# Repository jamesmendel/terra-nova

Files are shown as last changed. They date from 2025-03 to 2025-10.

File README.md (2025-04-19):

<h1 align="center">TERRA is a companion for mindful wandering</h1>
<h2 align="center">⭐️ This is the working repository for the second generation of TERRA hardware and software. ⭐️</h2>

<br> <!-- Additional spacing -->
<br> <!-- Additional spacing -->

<p align="center">
  TERRA Device
</p>

<br> <!-- Additional spacing -->
<br> <!-- Additional spacing -->

##  Designed with the science of AI and the wisdom of mindfulness, TERRA is the incredible, pocket-sized compass that lets you wander without getting lost. Leave your phone behind and reconnect with your surroundings.

<br> <!-- Additional spacing -->

### Features
- **Improvised Trails, Powered by AI**: Every journey begins with a prompt. TERRA’s sophisticated AI translates your intentions, available time, and precise location into a tailored trail of GPS coordinates. Users don't know where TERRA will take them; the only certainty is finding their way back to the starting point.
- **Wander Without Your Phone**: TERRA invites users to leave their smartphones behind and reconnect with their surroundings. The standalone device boasts a minimalist interface, featuring a tranquil compass needle and gentle haptic feedback to ensure users remain engaged with the present moment.  
- **Open-Source by Design**: TERRA is designed with a DIY mindset. Anyone can download the open-source software, 3D print the CAD designs, assemble the necessary hardware, and start wandering.

<br> <!-- Additional spacing -->

<p align="center">
  ⚠️ <strong>NOTICE</strong>: This project is currently in an experimental phase and is undergoing rapid developments ⚠️
</p>

<br> <!-- Additional spacing -->

### Software

The TERRA App generates coordinates or checkpoints from a starting point and an ideal trail length using the ChatGPT API.

### Running TERRA App Locally

#### Prerequisites 
- `Node.js` v21.5
- `body-parser` v1.20.2
- `cors` v2.8.5
- `express` v4.19.0
- `node-fetch` v3.3.2

To run the TERRA App locally, follow these steps:

1. **Implement ChatGPT API Key:** Obtain a [ChatGPT API key](https://platform.openai.com/) and replace ```YOUR_OPENAI_API_KEY``` with it in the ```server.js``` file.
2. **Implement Google Maps API Key:** Obtain a [Google Places API key](https://developers.google.com/maps/documentation/places/web-service/overview) and replace ```YOUR_MAPS_KEY``` with it in the ```index.js``` file.
3. **Run Locally:** To run the application, use the command:
    ```
    node server.js
    ```
4. **Load Application:** Open `index.html` in a browser to use the app for generating a route.
5. **Download config.h File:** Download the `config.h` file which contains the generated route configuration.
6. **Update Arduino Code:** Replace the `config.h` file in the Arduino code directory with the newly downloaded file.

### Hardware

The hardware for the TERRA project is based on an ESP32 device, equipped with a range of sensors for navigation and interaction.

### Components

The main components required are:

- ESP32 Feather V2 [link](https://learn.adafruit.com/adafruit-esp32-feather-v2/pinouts)
- Waveshare 1.28" Round LCD Display Module with GC9A01 Driver [link](https://www.waveshare.com/1.28inch-lcd-module.htm)
- Adafruit Push-button Power Switch [link](https://thepihut.com/products/adafruit-push-button-power-switch-breakout)
- Beitian BN 880 GPS module [link](https://store.beitian.com/products/beitian-compass-qmc5883l-amp2-6-pix4-pixhawk-gnss-gps-glonass-dual-flight-control-gps-module-bn-880q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)
- Adafruit DRV2605L Haptic Controller Breakout [link](https://learn.adafruit.com/adafruit-drv2605-haptic-controller-breakout/arduino-code)
- CMPS12 Compass [link](https://www.robot-electronics.co.uk/cmps12-tilt-compensated-magnetic-compass.html)
- Round Battery
- USB C charging port extender

### Wiring
Connect the components together in the following order:

| ESP32 Pin | Screen | Motor Driver | Compass | GPS | Push Button |
| --- | --- | --- | --- | --- | --- |
| 3V | VCC | VIN | VIN | VIN | |
| GND | GND | GND | GND | GND | GND |
| 19 (MOSI) | DIN | | | | |
| 4 (A5) | RST | | | | |
| 5 (SCK) | CLK | | | | |
| 12 | BL | | | | |
| 15 | CS | | | | |
| 32 (A7) | | | | | OFF |
| 33 | DC | | | | |
| SDA | | SDA | SDA | | |
| SCL | | SCL | SCL | | |
| RX | | | | TX  | |
| TX | | | | RX  | |

## Arduino Code

To run the Arduino code, you will need to set up the ESP32 board and install the necessary libraries.

### Setup Steps

1. **ESP32 Arduino Setup:** Add the ESP32 board to the Arduino IDE.
    - Go to **Arduino > Preferences**.
    - Add the following URL to the **Additional Boards Manager URLs**:
      ```
      https://raw.githubusercontent.com/espressif/arduino-esp32/gh-pages/package_esp32_dev_index.json
      ```
    - Select **Adafruit Feather ESP32 V2** as the board.

2. **Install Libraries:** Install the following libraries through the Library Manager in the Arduino IDE.
    - `TinyGPSPlus.h`
    - `TFT_eSPI.h`
    - `Adafruit_DRV2605.h`

3. **Upload the Code:** After installing the libraries and updating the `config.h` file with new coordinates, upload the code to the ESP32 device. The device should work without further adjustments.

4. **Debug Mode:** A `debugMode` flag is available in the code. To test the device with manual coordinates, set this flag to `true` and input coordinates into the serial monitor.

### Further Customizations

You can use your own checkpoint files by converting black and white images into a compatible format.

#### Using Your Own Checkpoint Files

- Convert static black and white, 240x240PX `.bmp` images to `.XBM` format using [this online tool](https://www.online-utility.org/image/convert/to/XBM).
- Open the XBM file in a text editor and copy the hexadecimal values included in the curly brackets.
- Replace the existing files in the `images/checkpoints` directory with your customized `.h` file.

### Contributors
Vision + Concept: Modem<br> 
Industrial Design: Panter&Tourron<br> 
Software + Hardware: Alice Stewart<br> 
Product Renderings: Côme Lart<br> 
Illustrations: Hugo Bernier<br> 
Campaign Teaser: Michael Willis

### License
TERRA is licensed under the GNU General Public License v3.0 © 2024 Modem

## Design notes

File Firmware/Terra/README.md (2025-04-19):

Clone Firmware repo:
```bash
git clone --filter=blob:none --no-checkout https://github.com/jamesmendel/terra-nova.git
cd terra-nova
git sparse-checkout init --cone
git sparse-checkout set Firmware
git checkout main
```

Install PlatformIO

Initialize the project:
```bash
cd Firmware/Terra
pio init --ide vscode
```

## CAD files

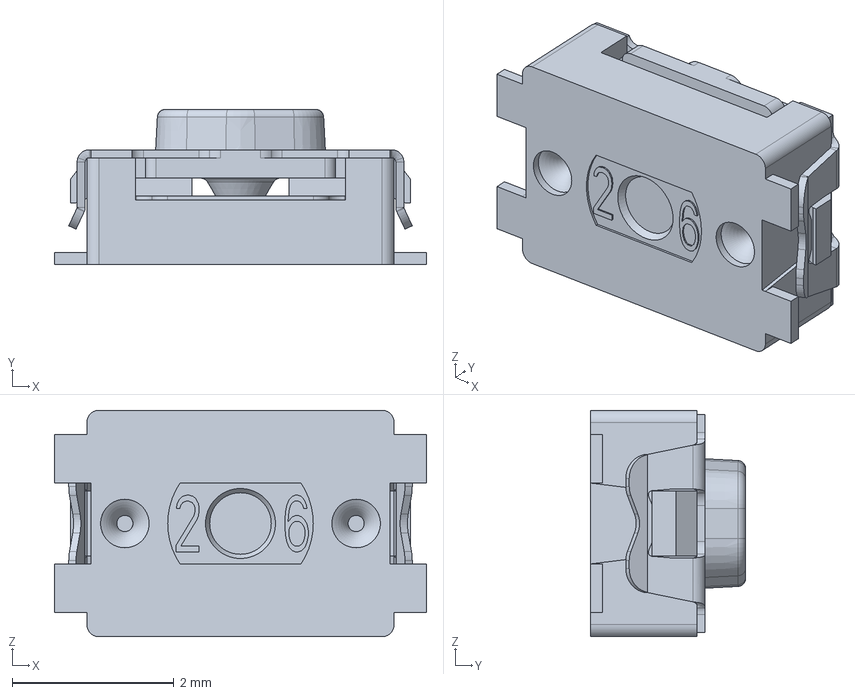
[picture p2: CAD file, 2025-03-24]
Hardware/Symbols/CKCOMPONENTS_KMR231NGULCLFS/KMR231NGULCLFS.stp
4.60 x 1.92 x 2.80 mm

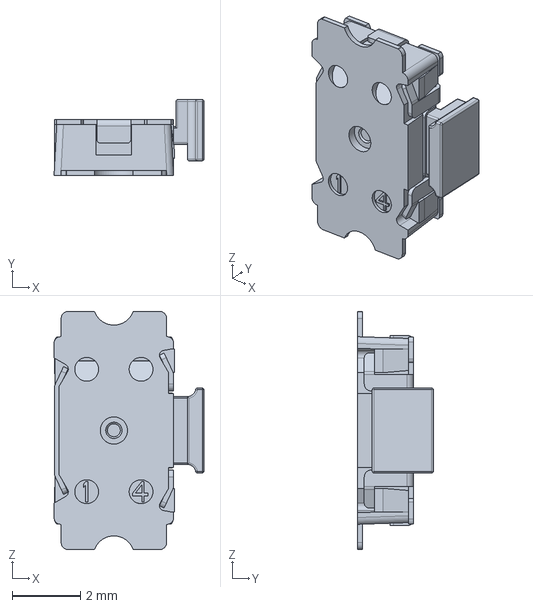
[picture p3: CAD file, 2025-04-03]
Hardware/Symbols/CKCOMPONENTS_KSS323GLFG/KSS323GLFG.stp
4.41 x 2.23 x 7.00 mm

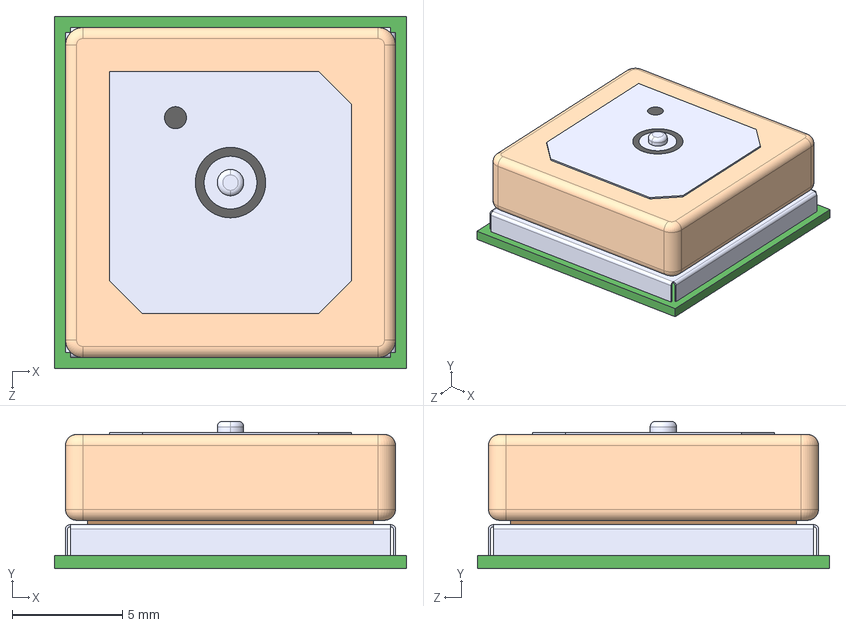
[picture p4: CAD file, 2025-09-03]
Hardware/Symbols/TESO-LIV3F/PA1616D.STEP
16.0 x 6.70 x 16.0 mm

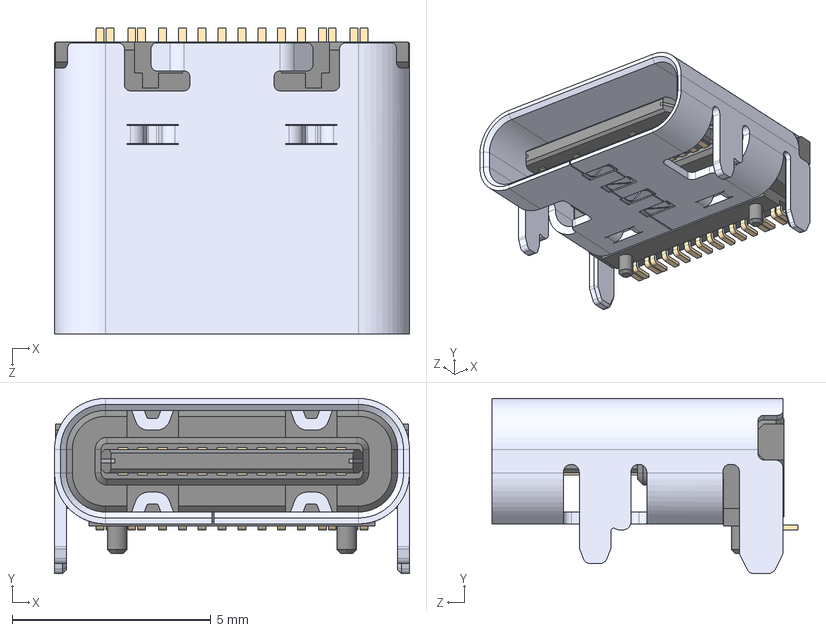
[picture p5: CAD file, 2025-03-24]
Hardware/Symbols/USB4105-GF-A.step
8.94 x 4.41 x 7.71 mm

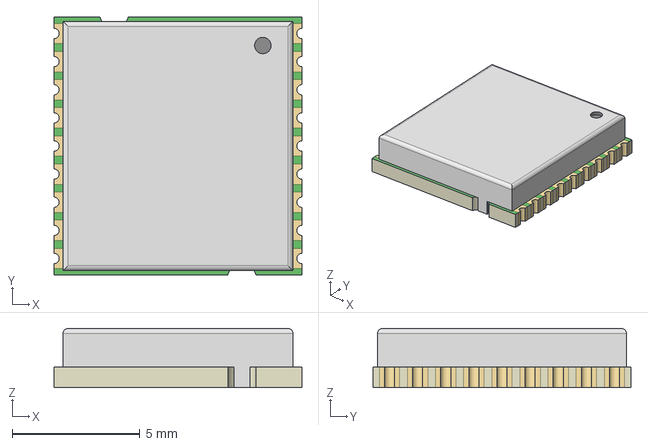
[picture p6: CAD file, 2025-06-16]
Hardware/Symbols/TESO-LIV3F/TESEO-LIV3R.stp
9.70 x 10.1 x 2.31 mm

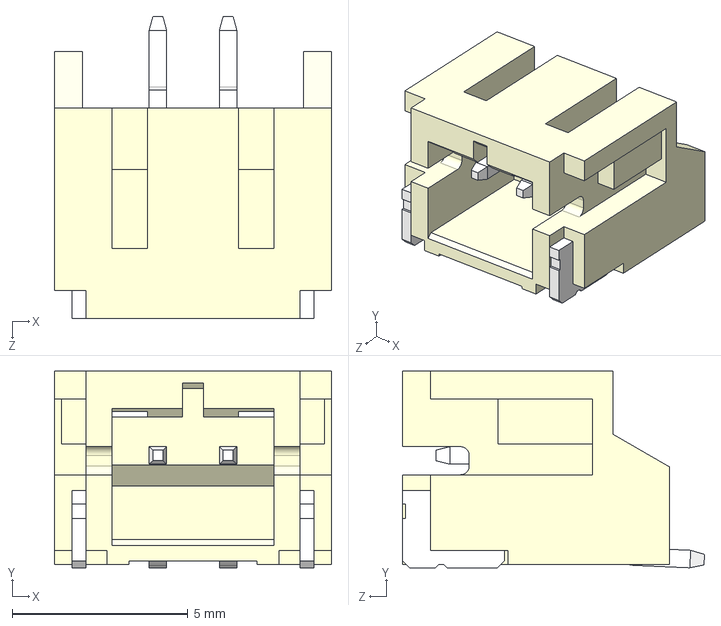
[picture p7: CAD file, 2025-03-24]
Hardware/Symbols/S2B-PH-SM4-TB.step
7.90 x 5.60 x 8.60 mm

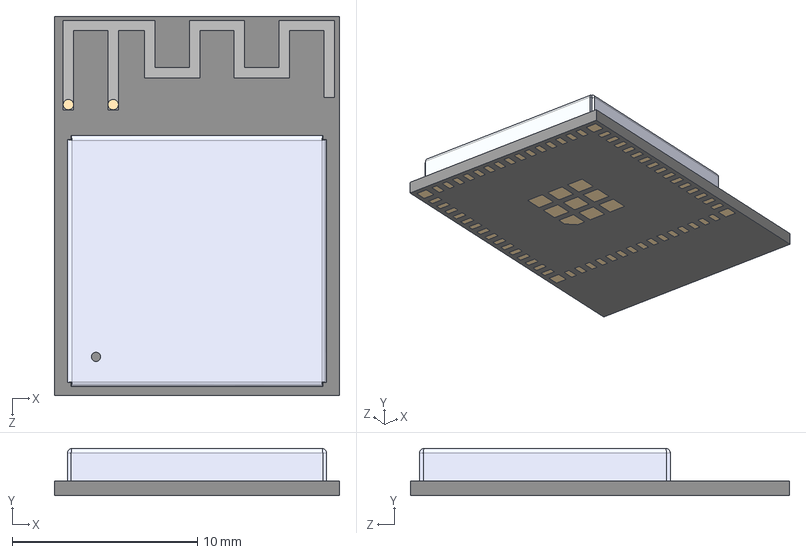
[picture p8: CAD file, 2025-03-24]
Hardware/Symbols/ESP32-S3-MINI-1-N8.step
15.4 x 2.55 x 20.5 mm

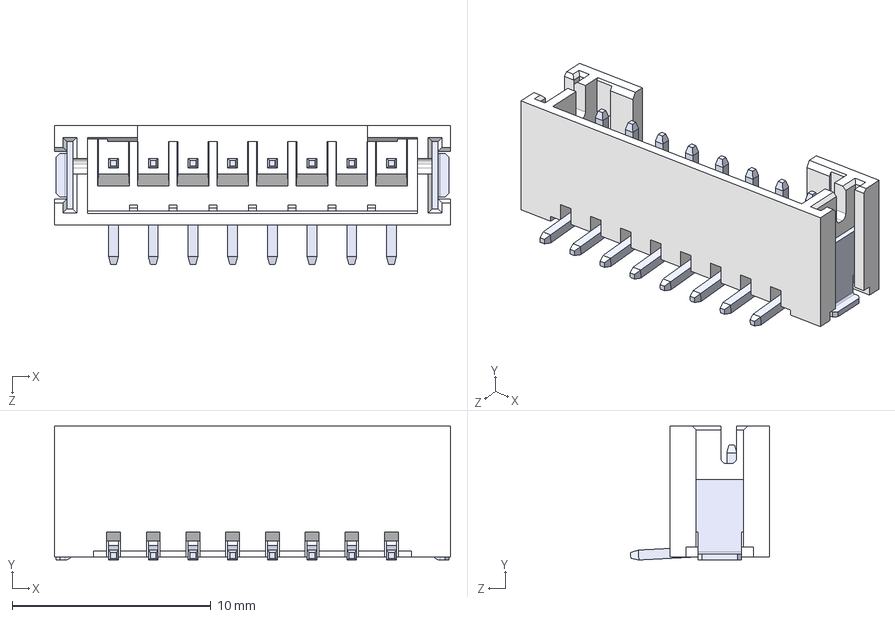
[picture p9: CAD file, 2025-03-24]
Hardware/Symbols/JST_PH_B8B-PH-SM4-TB_Vertical.STEP
20.0 x 6.75 x 7.00 mm
BxB-PH-SM4 body_8
BxB-PH-SM4 tab x 2
BxB-PH-SM4 pin x 8

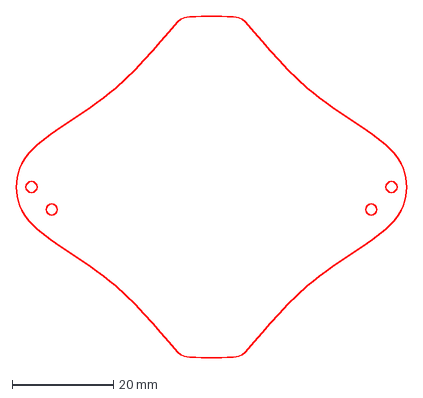
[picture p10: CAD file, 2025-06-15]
Hardware/Artwork/Outline/250506_Terra PCB Outline.dxf
76.9 x 67.3 mm

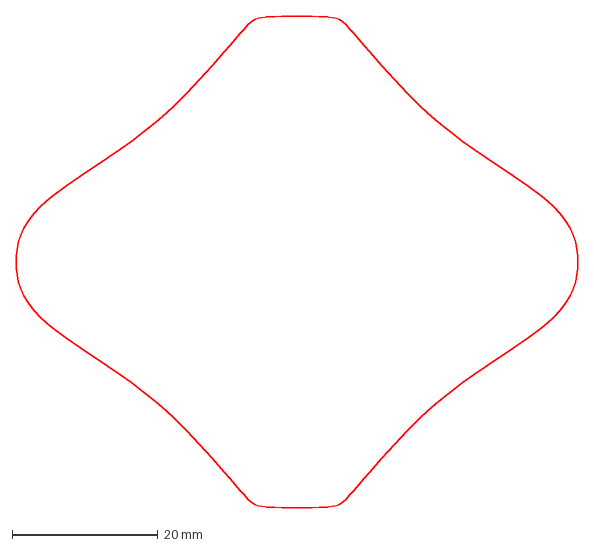
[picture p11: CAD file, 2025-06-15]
Hardware/Artwork/Outline/250506_Terra PCB Outline Only.dxf
76.9 x 67.3 mm

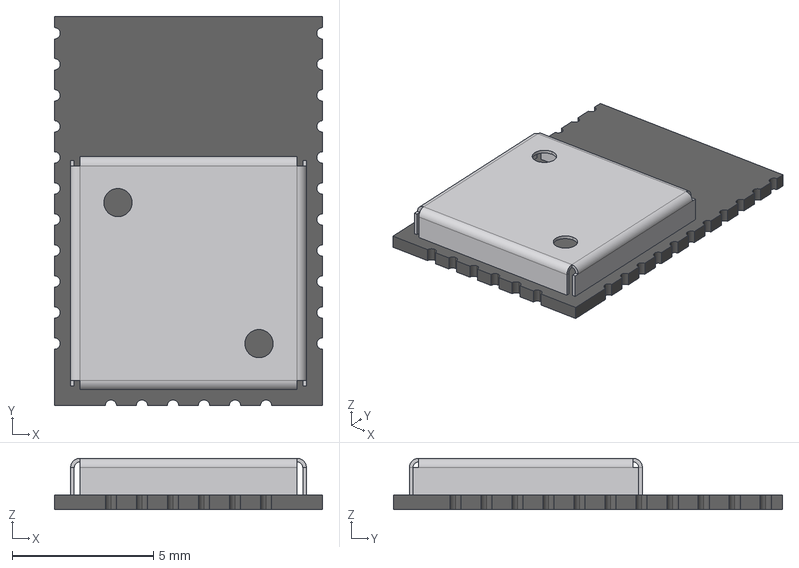
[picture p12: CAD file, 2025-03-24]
Hardware/Symbols/M20048-1_wshielding.step
9.50 x 13.8 x 1.82 mm

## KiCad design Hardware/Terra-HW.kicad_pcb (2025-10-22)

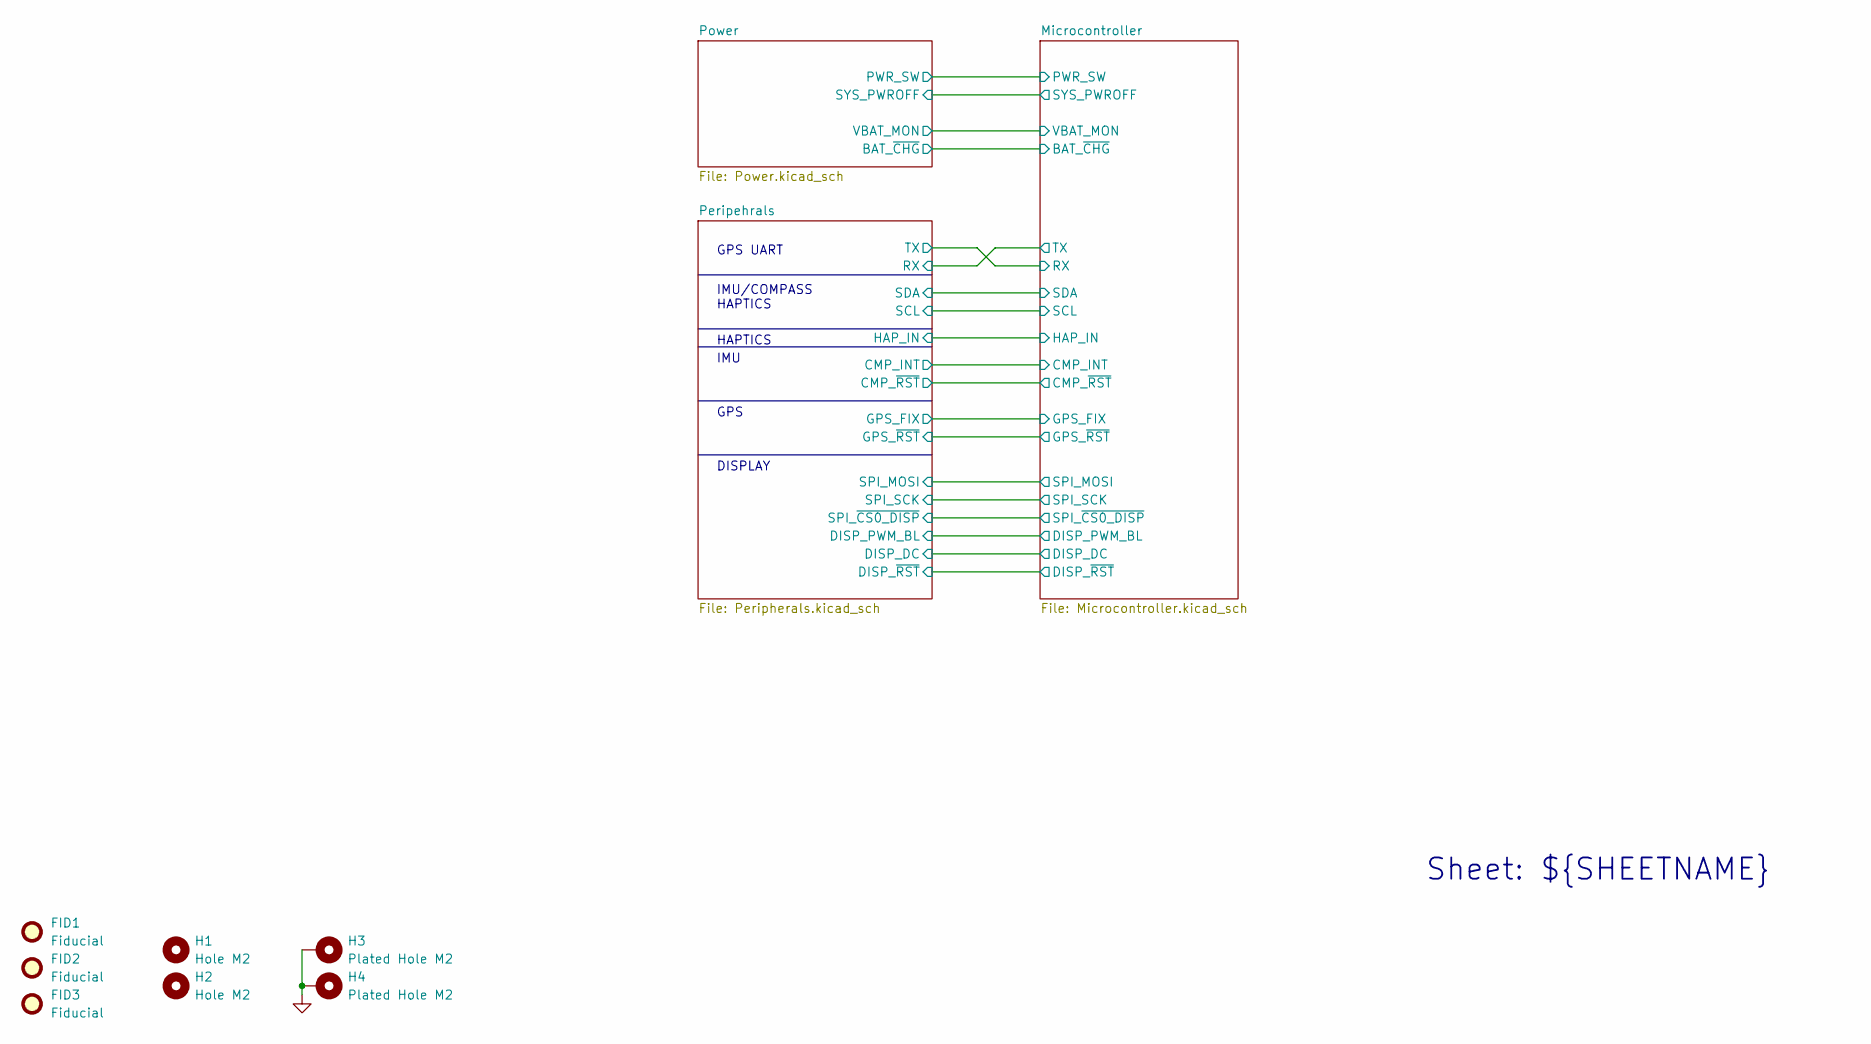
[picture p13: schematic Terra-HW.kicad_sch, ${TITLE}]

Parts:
FID1, FID2, FID3: Fiducial; Fiducial_1mm_Mask2mm
H1, H2: Hole M2; MountingHole_2.2mm_M2
H3, H4: Plated Hole M2; MountingHole_2.2mm_M2_Pad

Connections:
GND: H3.1, H4.1; also elsewhere on the board

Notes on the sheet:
HAPTICS
GPS UART
IMU
DISPLAY
IMU/COMPASS HAPTICS
GPS
Sheet: ${SHEETNAME}

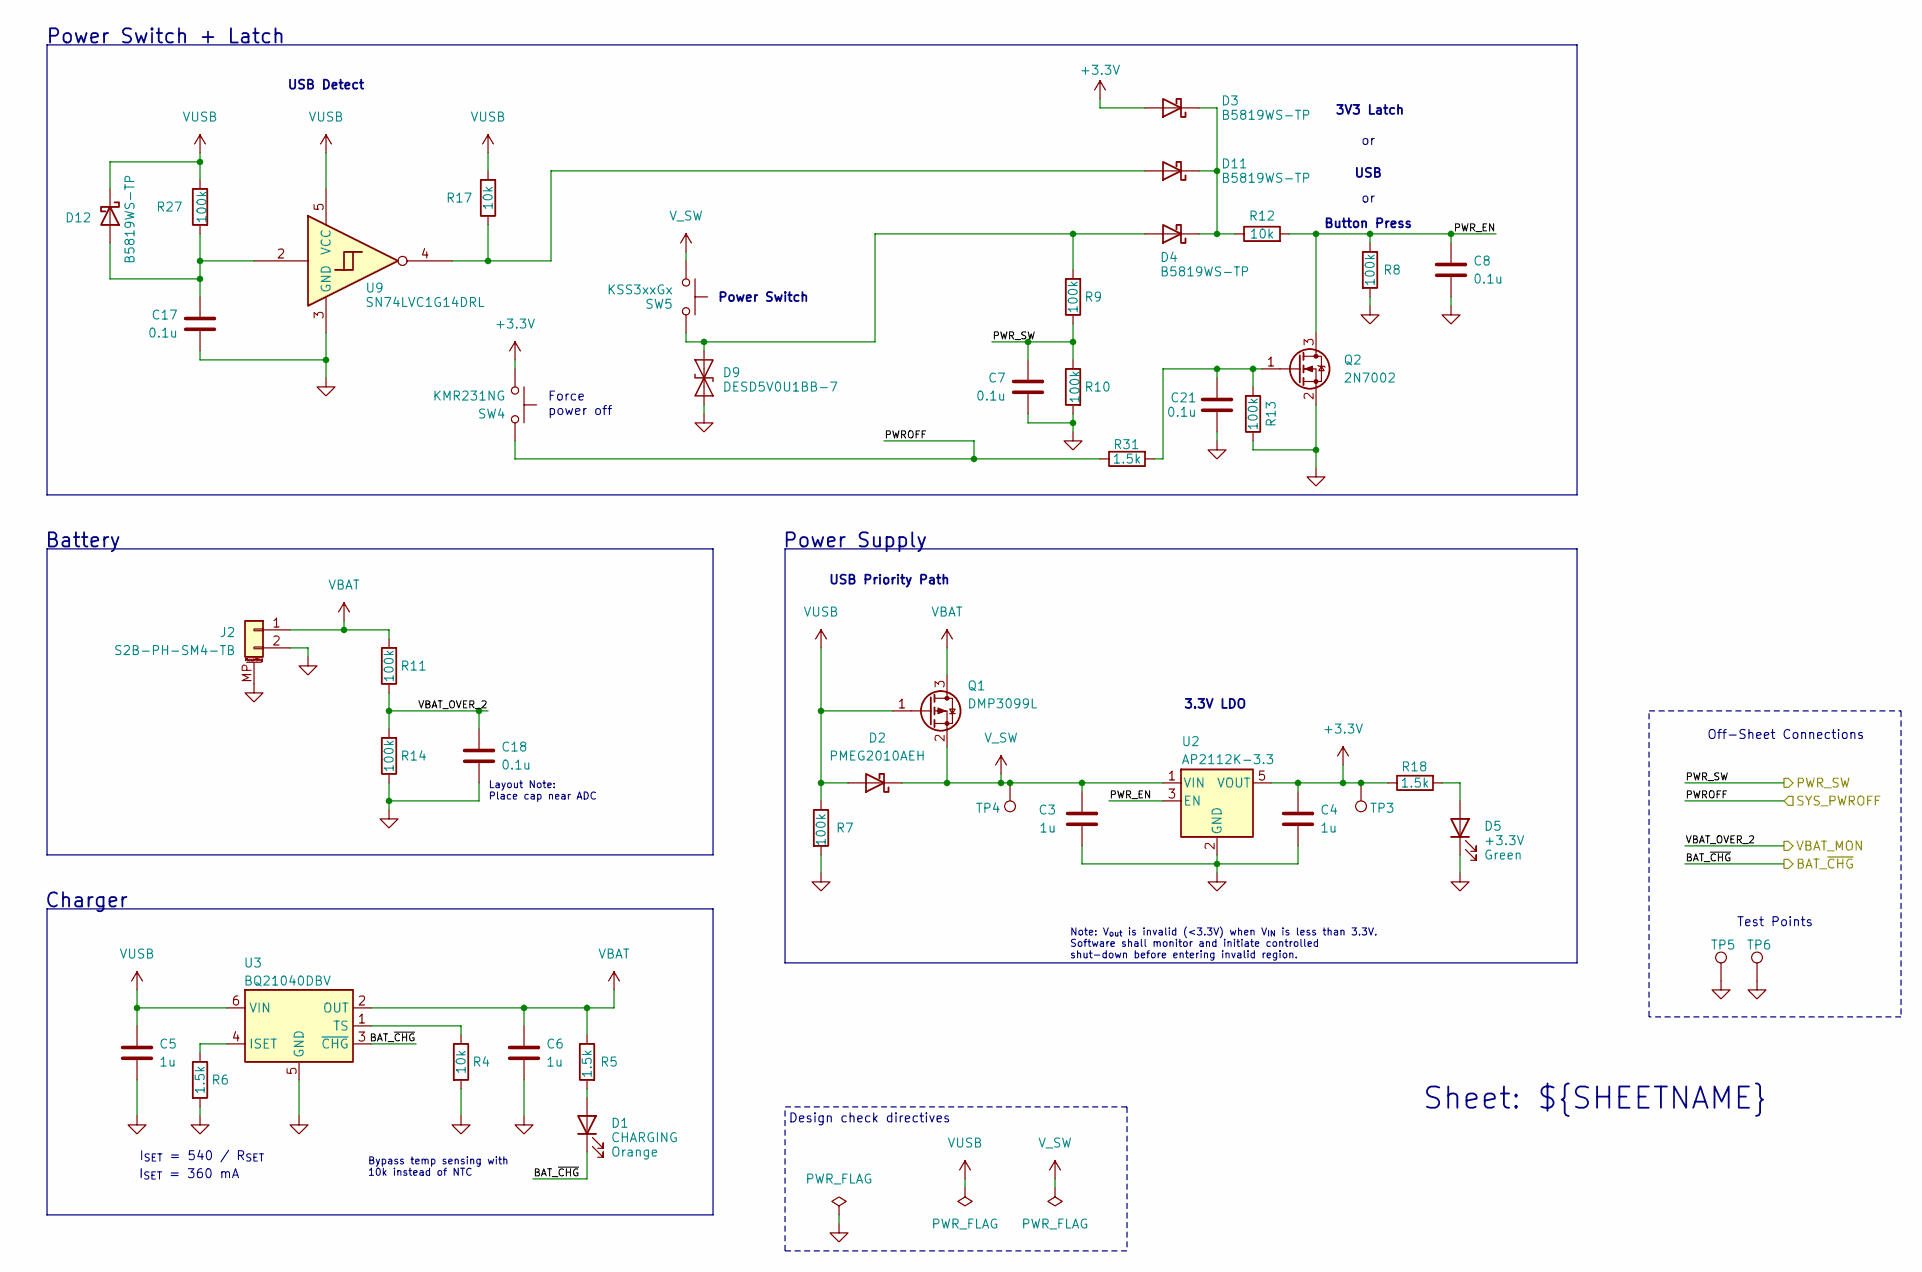
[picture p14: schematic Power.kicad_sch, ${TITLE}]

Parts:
C3, C4, C5, C6: 1u; C_0603_1608Metric; MPN CL10A105KO8NNNC
C7, C8, C17, C18, C21: 0.1u; C_0603_1608Metric; MPN CL10B104KO8NNNC
D1: CHARGING; D_0603_1608Metric; MPN LTST-C190KFKT
D2: PMEG2010AEH; D_SOD-123; MPN PMEG2010AEH
D3, D4, D11, D12: B5819WS-TP; D_SOD-323; MPN B5819WS-TP
D5: +3.3V; D_0603_1608Metric; MPN LTST-C190GKT
D9: DESD5V0U1BB-7; D_SOD-523; MPN DESD5V0U1BB-7
J2: S2B-PH-SM4-TB; JST_PH_S2B-PH-SM4-TB_1x02-1MP_P2.00mm_Horizontal; MPN S2B-PH-SM4-TB
Q1: DMP3099L; SOT-23; MPN DMP3099L
Q2: 2N7002; SOT-23; MPN 2N7002
R4, R12, R17: 10k; R_0603_1608Metric; MPN RC0603FR-0710KL
R5, R6, R18, R31: 1.5k; R_0603_1608Metric; MPN RC0603FR-071K5L
R7, R8, R9, R10, R11, R13, R14, R27: 100k; R_0603_1608Metric; MPN RC0603FR-07100KL
SW4: KMR231NG; SW_Push_1P1T_NO_CK_KMR2; MPN KMR231NG
SW5: KSS3xxGx; SW_KSS323_CNK; MPN KSS321GLFS
TP3: 3.3V; TestPoint_Pad_D1.5mm_WITH_LABEL
TP4: V_SW; TestPoint_Pad_D1.5mm_WITH_LABEL
TP5, TP6: GND; TestPoint_Pad_D1.5mm_WITH_LABEL
U2: AP2112K-3.3; SOT-23-5; MPN AP2112K-3.3TRG1
U3: BQ21040DBV; SOT-23-6; MPN BQ21040DBV
U9: SN74LVC1G14DRL; SOT-553; MPN SN74LVC1G14DRL

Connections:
+3.3V: C4.1, D3.2 (A), R18.1, SW4.1, TP3.1, U2.5 (VOUT); also elsewhere on the board
/Microcontroller/BAT_~CHG: D1.1 (K), U3.3 (~CHG); also elsewhere on the board
/Microcontroller/PWROFF: R31.1, SW4.2; also elsewhere on the board
/Microcontroller/PWR_SW: C7.1, R9.1, R10.1; also elsewhere on the board
/Microcontroller/VBAT_OVER_2: C18.1, R11.1, R14.2; also elsewhere on the board
/Power/PWR_EN: C8.1, Q2.3 (D), R8.1, R12.2, U2.3 (EN)
GND: C3.2, C4.2, C5.2, C6.2, C7.2, C8.2, C17.2, C18.2, C21.2, D5.1 (K), D9.1 (A1), J2.2, J2.MP (MountPin), Q2.2 (S), R4.2, R6.2, R7.2, R8.2, R10.2, R13.1, R14.1, TP5.1, TP6.1, U2.2 (GND), U3.5 (GND), U9.3 (GND); also elsewhere on the board
unnamed: D1.2 (A), R5.2
unnamed: D4.2 (A), D9.2 (A2), R9.2, SW5.2
unnamed: D5.2 (A), R18.2
unnamed: D11.2 (A), R17.1, U9.4
unnamed: D3.1 (K), D4.1 (K), D11.1 (K), R12.1
unnamed: C17.1, D12.2 (A), R27.2, U9.2
unnamed: C21.1, Q2.1 (G), R13.2, R31.2
unnamed: R6.1, U3.4 (ISET)
unnamed: R4.1, U3.1 (TS)
VBAT: C6.1, J2.1, Q1.3 (D), R5.1, R11.2, U3.2 (OUT); also elsewhere on the board
VUSB: C5.1, D2.2 (A), D12.1 (K), Q1.1 (G), R7.1, R17.2, R27.1, U3.6 (VIN), U9.5 (VCC); also elsewhere on the board
V_SW: C3.1, D2.1 (K), Q1.2 (S), SW5.1, TP4.1, U2.1 (VIN)

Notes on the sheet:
Power Switch
Power Supply
I_{SET} = 540 / R_{SET}
3V3 Latch
3.3V LDO
USB Priority Path
Note: V_{out} is invalid (<3.3V) when V_{IN} is less than 3.3V. Software shall monitor and initiate controlled shut-down before entering invalid region.
Force power off
Test Points
Bypass temp sensing with 10k instead of NTC
Charger
Design check directives
I_{SET} = 360 mA
Button Press
Layout Note: Place cap near ADC
USB Detect
Battery
Off-Sheet Connections
USB
Power Switch + Latch
Sheet: ${SHEETNAME}

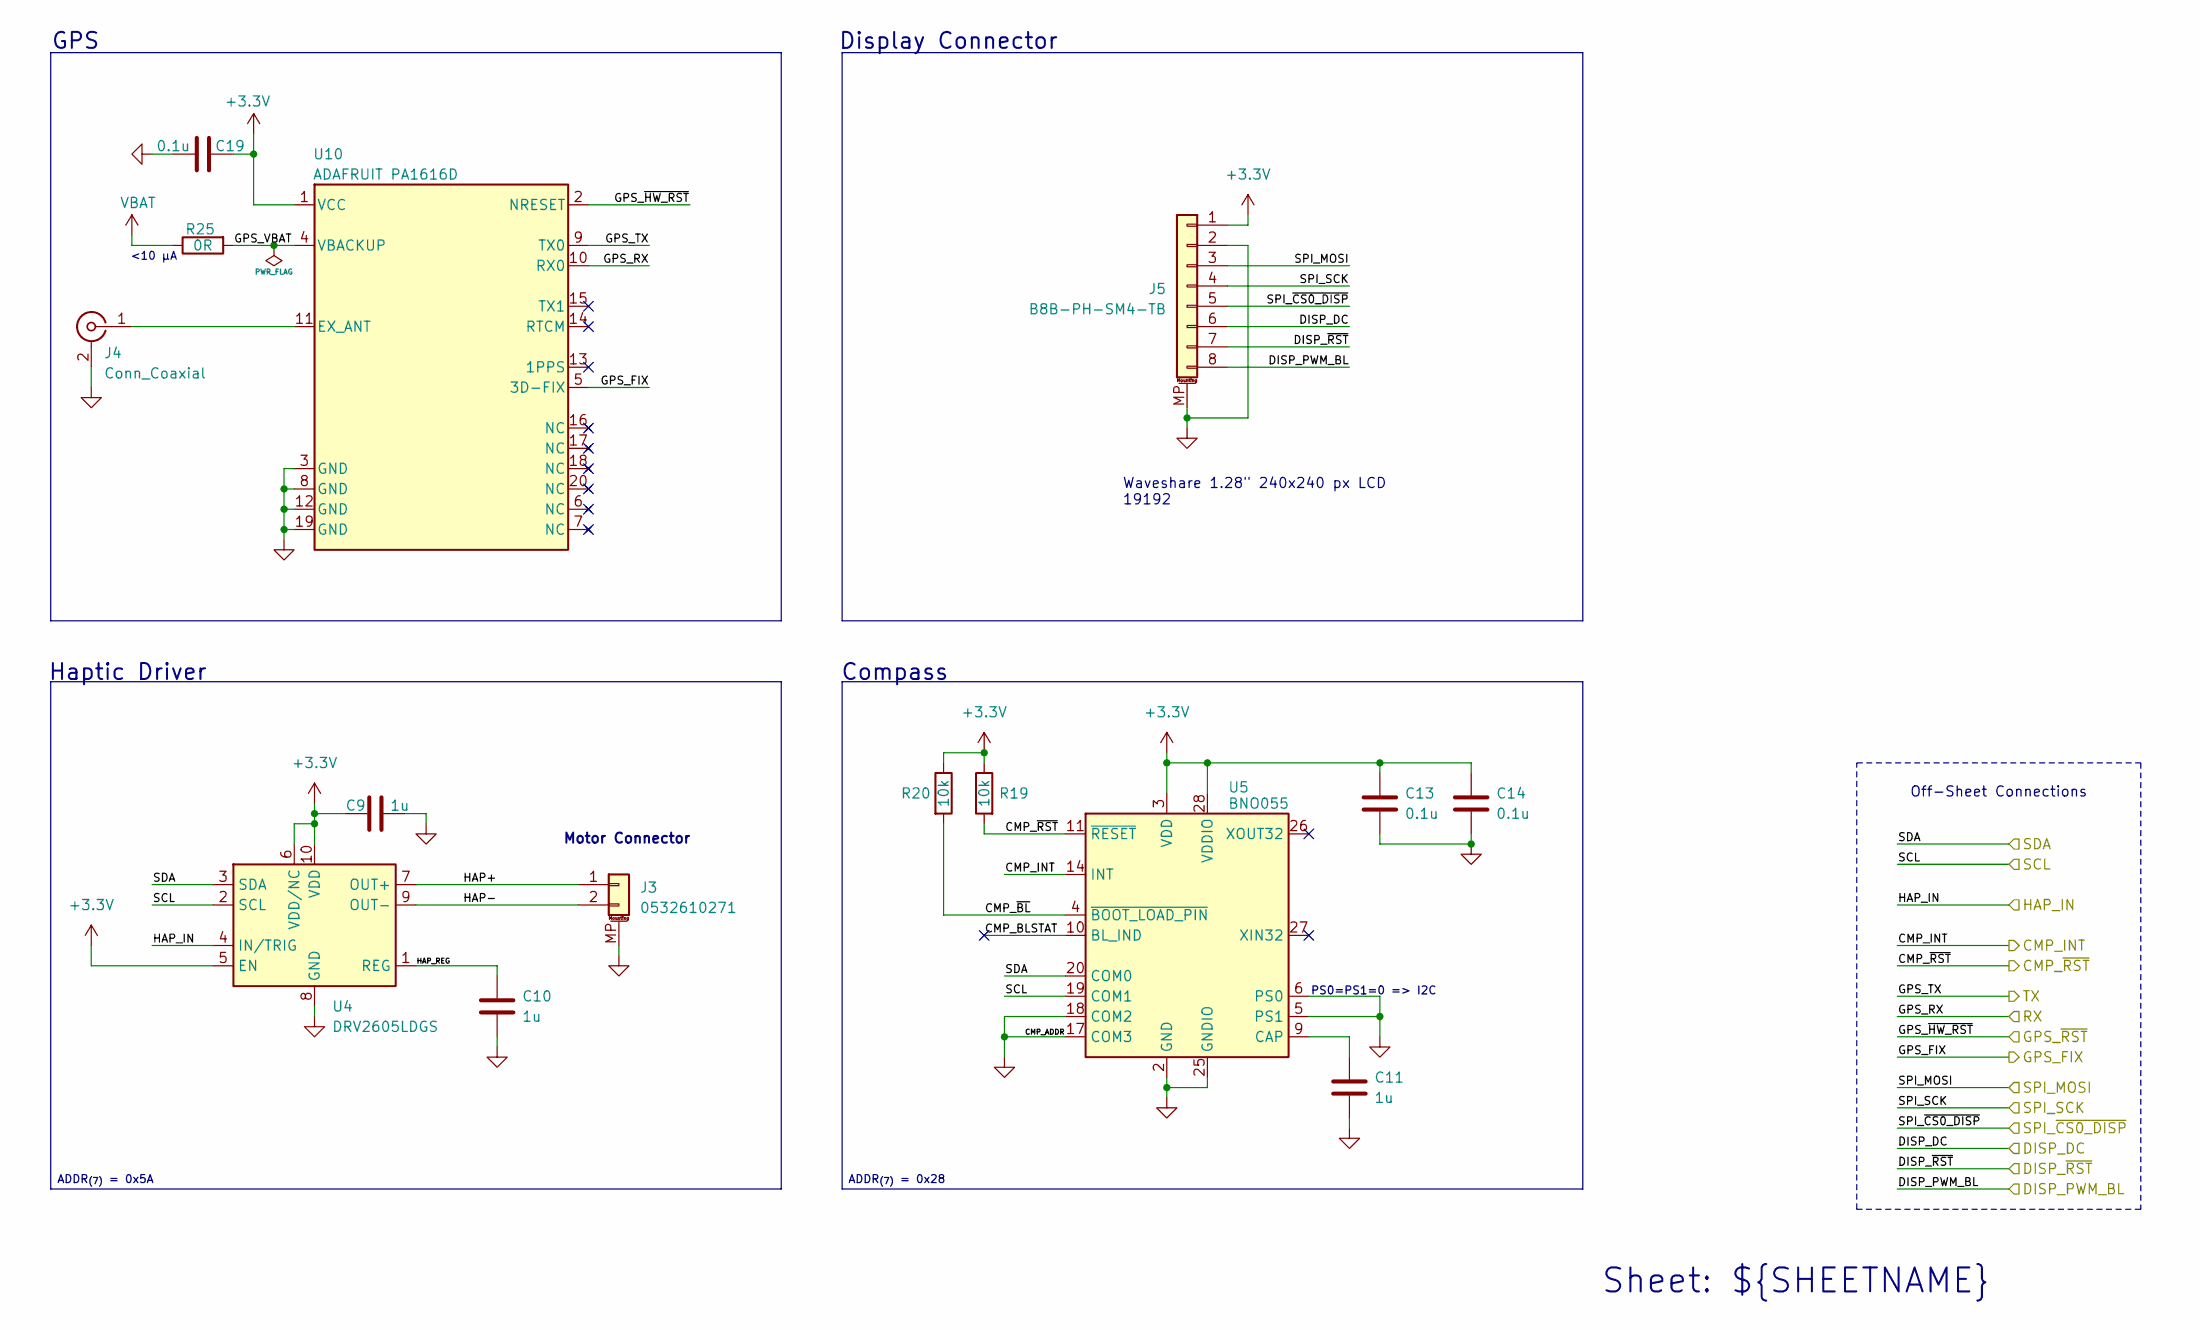
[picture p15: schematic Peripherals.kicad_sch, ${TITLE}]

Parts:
C9, C10, C11: 1u; C_0603_1608Metric; MPN CL10A105KO8NNNC
C13, C14, C19: 0.1u; C_0603_1608Metric; MPN CL10B104KO8NNNC
J3: 0532610271; Molex_PicoBlade_53261-0271_1x02-1MP_P1.25mm_Horizontal; MPN 0532610271
J4: Conn_Coaxial; U.FL_Molex_MCRF_73412-0110_Vertical; MPN CONMHF1-SMD-T
J5: B8B-PH-SM4-TB; JST_PH_B8B-PH-SM4-TB_1x08-1MP_P2.00mm_Vertical; MPN B8B-PH-SM4-TB
R19, R20: 10k; R_0603_1608Metric; MPN RC0603FR-0710KL
R25: 0R; R_0603_1608Metric; MPN RC0603FR-070RL
U4: DRV2605LDGS; VSSOP-10_3x3mm_P0.5mm; MPN DRV2605LDGS
U5: BNO055; LGA-28_5.2x3.8mm_P0.5mm; MPN BNO055
U10: ADAFRUIT PA1616D; PA1616D; MPN 5186

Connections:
+3.3V: C9.1, C13.1, C14.1, C19.1, J5.1, R19.1, R20.1, U4.5 (EN), U4.6 (VDD/NC), U4.10 (VDD), U5.3 (VDD), U5.28 (VDDIO), U10.1 (VCC); also elsewhere on the board
/Microcontroller/CMP_INT: U5.14 (INT); also elsewhere on the board
/Microcontroller/CMP_~RST: R19.2, U5.11 (~RESET); also elsewhere on the board
/Microcontroller/DISP_DC: J5.6; also elsewhere on the board
/Microcontroller/DISP_PWM_BL: J5.8; also elsewhere on the board
/Microcontroller/DISP_~RST: J5.7; also elsewhere on the board
/Microcontroller/GPS_FIX: U10.5 (3D-FIX); also elsewhere on the board
/Microcontroller/GPS_~RST: U10.2 (NRESET); also elsewhere on the board
/Microcontroller/HAPTIC_IN_TRG: U4.4 (IN/TRIG); also elsewhere on the board
/Microcontroller/I2C_SCL: U4.2 (SCL), U5.19 (COM1); also elsewhere on the board
/Microcontroller/I2C_SDA: U4.3 (SDA), U5.20 (COM0); also elsewhere on the board
/Microcontroller/SPI_MOSI: J5.3; also elsewhere on the board
/Microcontroller/SPI_SCK: J5.4; also elsewhere on the board
/Microcontroller/SPI_~CS0_DISP: J5.5; also elsewhere on the board
/Microcontroller/U1RXD: U10.9 (TX0); also elsewhere on the board
/Microcontroller/U1TXD: U10.10 (RX0); also elsewhere on the board
/Peripehrals/CMP_BLSTAT: U5.10 (BL_IND)
/Peripehrals/CMP_~BL: R20.2, U5.4 (~BOOT_LOAD_PIN)
/Peripehrals/GPS_VBAT: R25.2, U10.4 (VBACKUP)
/Peripehrals/HAP+: J3.1, U4.7 (OUT+)
/Peripehrals/HAP-: J3.2, U4.9 (OUT-)
/Peripehrals/HAP_REG: C10.1, U4.1 (REG)
GND: C9.2, C10.2, C11.2, C13.2, C14.2, C19.2, J3.MP (MountPin), J4.2 (Ext), J5.2, J5.MP (MountPin), U4.8 (GND), U5.2 (GND), U5.5 (PS1), U5.6 (PS0), U5.17 (COM3), U5.18 (COM2), U5.25 (GNDIO), U10.3 (GND), U10.8 (GND), U10.12 (GND), U10.19 (GND); also elsewhere on the board
unnamed: J4.1 (In), U10.11 (EX_ANT)
unnamed: C11.1, U5.9 (CAP)
VBAT: R25.1; also elsewhere on the board

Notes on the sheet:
ADDR_{(7)} = 0x5A
ADDR_{(7)} = 0x28
Off-Sheet Connections
Waveshare 1.28" 240x240 px LCD 19192
Motor Connector
Compass
GPS
<10 μA
PS0=PS1=0 => I2C
Haptic Driver
Display Connector
Sheet: ${SHEETNAME}

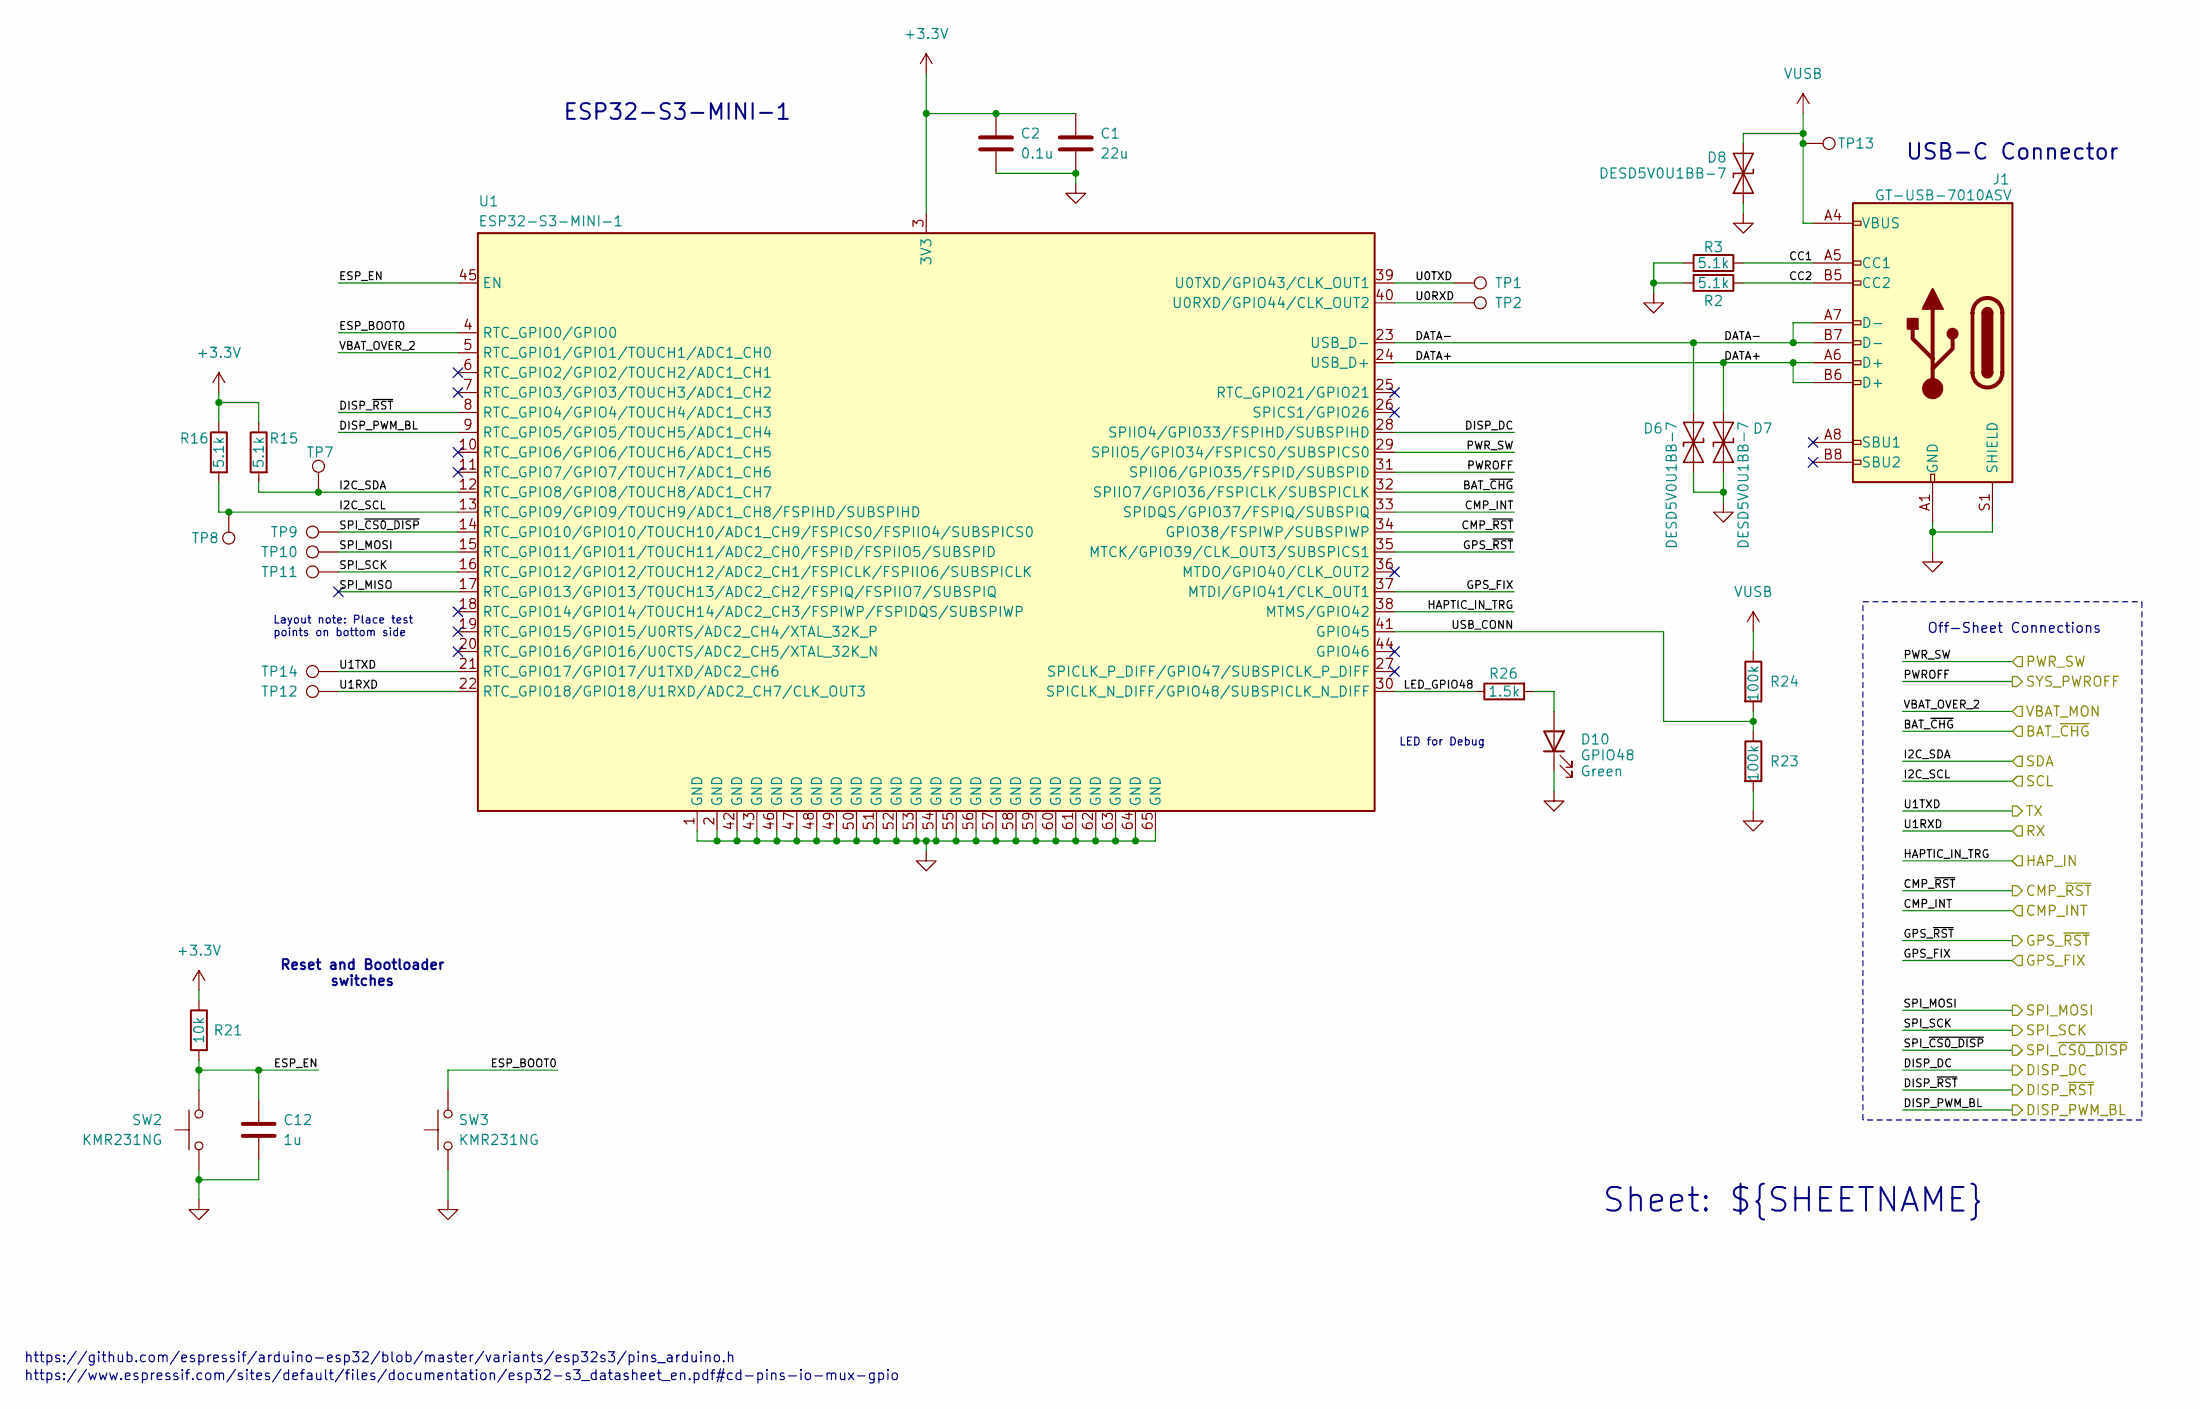
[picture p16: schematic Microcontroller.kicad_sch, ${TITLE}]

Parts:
C1: 22u; C_0603_1608Metric; MPN CL10A226MP8NUNE
C2: 0.1u; C_0603_1608Metric; MPN CL10B104KO8NNNC
C12: 1u; C_0603_1608Metric; MPN CL10A105KO8NNNC
D6, D7, D8: DESD5V0U1BB-7; D_SOD-523; MPN DESD5V0U1BB-7
D10: GPIO48; D_0603_1608Metric; MPN LTST-C190GKT
J1: GT-USB-7010ASV; USB_C_Receptacle_G-Switch_GT-USB-7010ASV; MPN GT-USB-7010ASV
R2, R3, R15, R16: 5.1k; R_0603_1608Metric; MPN RC0603FR-075K1L
R21: 10k; R_0603_1608Metric; MPN RC0603FR-0710KL
R23, R24: 100k; R_0603_1608Metric; MPN RC0603FR-07100KL
R26: 1.5k; R_0603_1608Metric; MPN RC0603FR-071K5L
SW2, SW3: KMR231NG; SW_Push_1P1T_NO_CK_KMR2; MPN KMR231NG
TP1: TXD0; TestPoint_Pad_D1.5mm_WITH_LABEL
TP2: RXD0; TestPoint_Pad_D1.5mm_WITH_LABEL
TP7: I2C_SDA; TestPoint_Pad_D1.5mm_WITH_LABEL
TP8: I2C_SCL; TestPoint_Pad_D1.5mm_WITH_LABEL
TP9: SPI_CS0; TestPoint_Pad_D1.5mm_WITH_LABEL
TP10: SPI_MOSI; TestPoint_Pad_D1.5mm_WITH_LABEL
TP11: SPI_SCK; TestPoint_Pad_D1.5mm_WITH_LABEL
TP12: RXD1; TestPoint_Pad_D1.5mm_WITH_LABEL
TP13: VUSB; TestPoint_Pad_D1.5mm_WITH_LABEL
TP14: TXD1; TestPoint_Pad_D1.5mm_WITH_LABEL
U1: ESP32-S3-MINI-1; ESP32-S2-MINI-1; MPN ESP32-S3-MINI-1-N4R2

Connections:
+3.3V: C1.1, C2.1, R15.1, R16.1, R21.1, U1.3 (3V3); also elsewhere on the board
/Microcontroller/BAT_~CHG: U1.32 (SPIIO7/GPIO36/FSPICLK/SUBSPICLK); also elsewhere on the board
/Microcontroller/CC1: J1.A5 (CC1), R3.1
/Microcontroller/CC2: J1.B5 (CC2), R2.1
/Microcontroller/CMP_INT: U1.33 (SPIDQS/GPIO37/FSPIQ/SUBSPIQ); also elsewhere on the board
/Microcontroller/CMP_~RST: U1.34 (GPIO38/FSPIWP/SUBSPIWP); also elsewhere on the board
/Microcontroller/DATA+: D7.2 (A2), J1.A6 (D+), J1.B6 (D+), U1.24 (USB_D+)
/Microcontroller/DATA-: D6.2 (A2), J1.A7 (D-), J1.B7 (D-), U1.23 (USB_D-)
/Microcontroller/DISP_DC: U1.28 (SPIIO4/GPIO33/FSPIHD/SUBSPIHD); also elsewhere on the board
/Microcontroller/DISP_PWM_BL: U1.9 (RTC_GPIO5/GPIO5/TOUCH5/ADC1_CH4); also elsewhere on the board
/Microcontroller/DISP_~RST: U1.8 (RTC_GPIO4/GPIO4/TOUCH4/ADC1_CH3); also elsewhere on the board
/Microcontroller/ESP_BOOT0: SW3.2, U1.4 (RTC_GPIO0/GPIO0)
/Microcontroller/ESP_EN: C12.1, R21.2, SW2.2, U1.45 (EN)
/Microcontroller/GPS_FIX: U1.37 (MTDI/GPIO41/CLK_OUT1); also elsewhere on the board
/Microcontroller/GPS_~RST: U1.35 (MTCK/GPIO39/CLK_OUT3/SUBSPICS1); also elsewhere on the board
/Microcontroller/HAPTIC_IN_TRG: U1.38 (MTMS/GPIO42); also elsewhere on the board
/Microcontroller/I2C_SCL: R16.2, TP8.1, U1.13 (RTC_GPIO9/GPIO9/TOUCH9/ADC1_CH8/FSPIHD/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); also elsewhere on the board
/Microcontroller/I2C_SDA: R15.2, TP7.1, U1.12 (RTC_GPIO8/GPIO8/TOUCH8/ADC1_CH7); also elsewhere on the board
/Microcontroller/LED_GPIO48: R26.1, U1.30 (SPICLK_N_DIFF/GPIO48/SUBSPICLK_N_DIFF)
/Microcontroller/PWROFF: U1.31 (SPIIO6/GPIO35/FSPID/SUBSPID); also elsewhere on the board
/Microcontroller/PWR_SW: U1.29 (SPIIO5/GPIO34/FSPICS0/SUBSPICS0); also elsewhere on the board
/Microcontroller/SPI_MISO: U1.17 (RTC_GPIO13/GPIO13/TOUCH13/ADC2_CH2/FSPI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)
/Microcontroller/SPI_MOSI: TP10.1, U1.15 (RTC_GPIO11/GPIO11/TOUCH11/ADC2_CH0/FSPI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); also elsewhere on the board
/Microcontroller/SPI_SCK: TP11.1, U1.16 (RTC_GPIO12/GPIO12/TOUCH12/ADC2_CH1/FSPI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); also elsewhere on the board
/Microcontroller/SPI_~CS0_DISP: TP9.1, U1.14 (RTC_GPIO10/GPIO10/TOUCH10/ADC1_CH9/FSPI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); also elsewhere on the board
/Microcontroller/U0RXD: TP2.1, U1.40 (U0RXD/GPIO44/CLK_OUT2)
/Microcontroller/U0TXD: TP1.1, U1.39 (U0TXD/GPIO43/CLK_OUT1)
/Microcontroller/U1RXD: TP12.1, U1.22 (RTC_GPIO18/GPIO18/U1RXD/ADC2_CH7/CLK_OU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); also elsewhere on the board
/Microcontroller/U1TXD: TP14.1, U1.21 (RTC_GPIO17/GPIO17/U1TXD/ADC2_CH6); also elsewhere on the board
/Microcontroller/USB_CONN: R23.1, R24.2, U1.41 (GPIO45)
/Microcontroller/VBAT_OVER_2: U1.5 (RTC_GPIO1/GPIO1/TOUCH1/ADC1_CH0); also elsewhere on the board
GND: C1.2, C2.2, C12.2, D6.1 (A1), D7.1 (A1), D8.1 (A1), D10.1 (K), J1.A1 (GND), J1.A12 (GND), J1.B1 (GND), J1.B12 (GND), J1.S1 (SHIELD), R2.2, R3.2, R23.2, SW2.1, SW3.1, U1.1 (GND), U1.2 (GND), U1.42 (GND), U1.43 (GND), U1.46 (GND), U1.47 (GND), U1.48 (GND), U1.49 (GND), U1.50 (GND), U1.51 (GND), U1.52 (GND), U1.53 (GND), U1.54 (GND), U1.55 (GND), U1.56 (GND), U1.57 (GND), U1.58 (GND), U1.59 (GND), U1.60 (GND), U1.61 (GND), U1.62 (GND), U1.63 (GND), U1.64 (GND), U1.65 (GND); also elsewhere on the board
unnamed: D10.2 (A), R26.2
VUSB: D8.2 (A2), J1.A4 (VBUS), J1.A9 (VBUS), J1.B4 (VBUS), J1.B9 (VBUS), R24.1, TP13.1; also elsewhere on the board

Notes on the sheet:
https://github.com/espressif/arduino-esp32/blob/master/variants/esp32s3/pins_arduino.h
Reset and Bootloader switches
https://www.espressif.com/sites/default/files/documentation/esp32-s3_datasheet_en.pdf#cd-pins-io-mux-gpio
Layout note: Place test points on bottom side
USB-C Connector
ESP32-S3-MINI-1
Off-Sheet Connections
LED for Debug
Sheet: ${SHEETNAME}

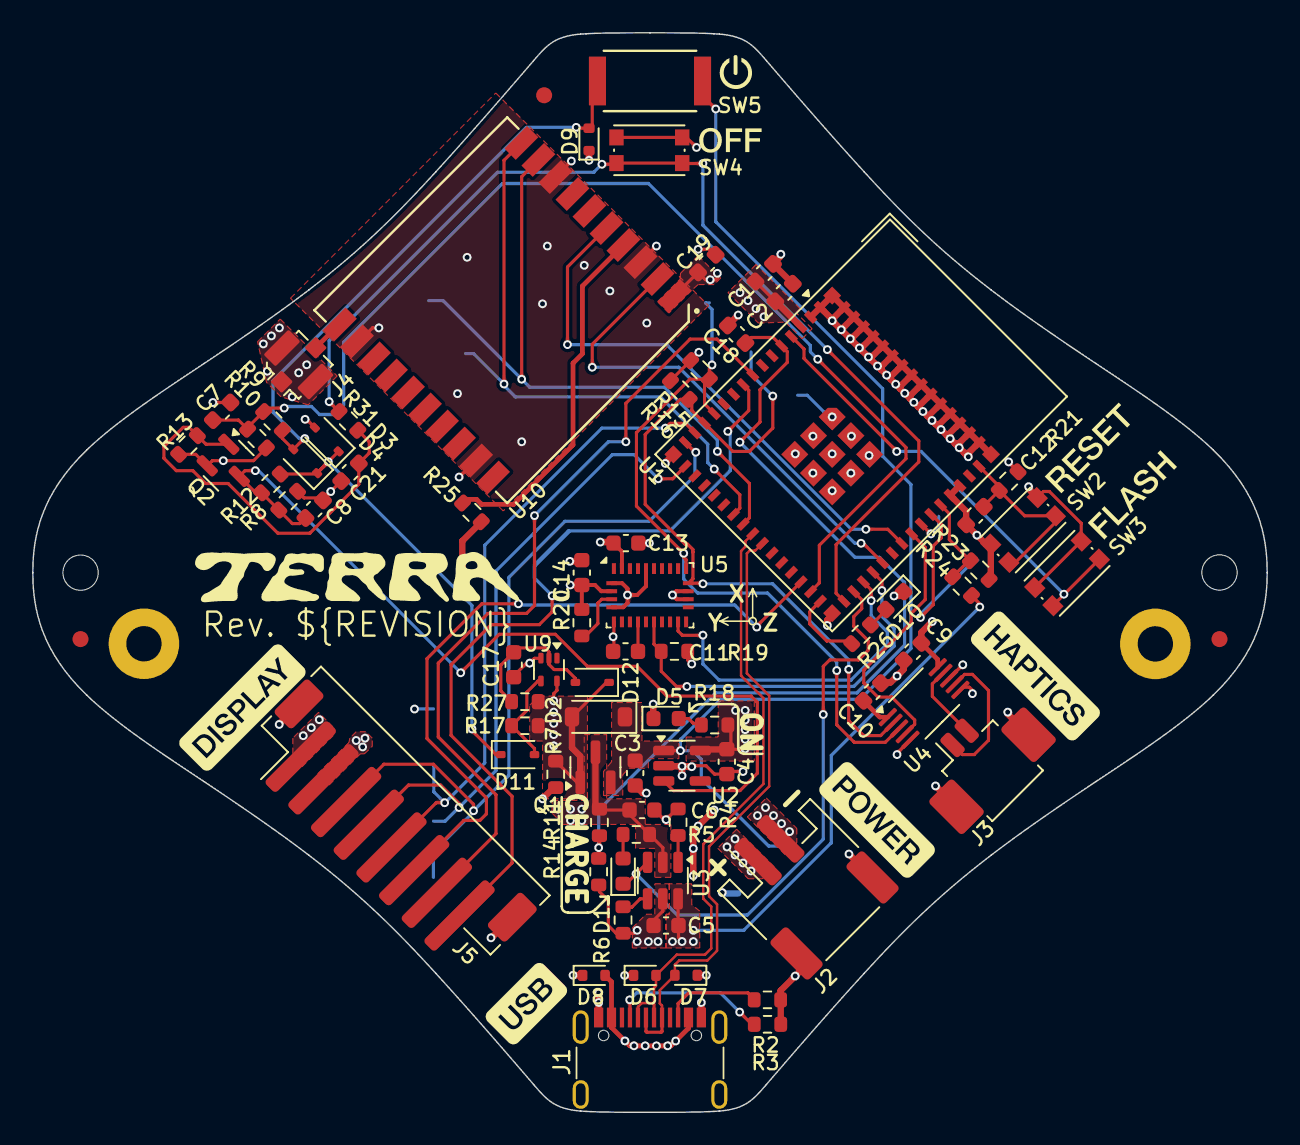
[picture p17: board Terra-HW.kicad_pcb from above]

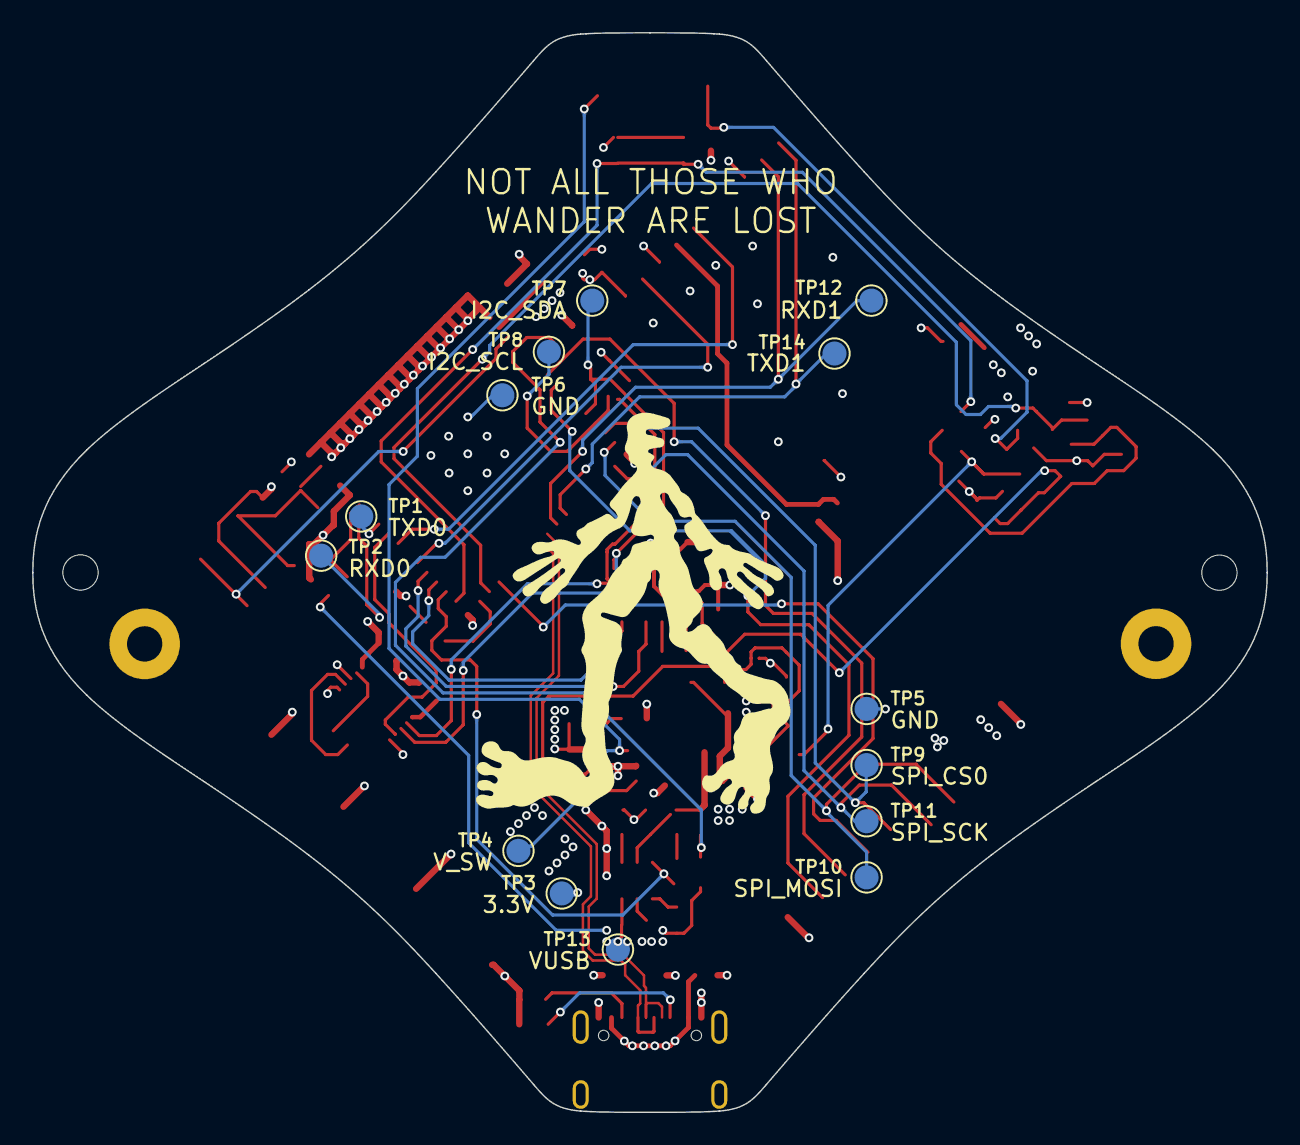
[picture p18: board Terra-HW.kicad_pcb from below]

Board: 4 copper layers, 76.9 x 67.3 mm, 95 parts (14 on the bottom side), 52 nets.

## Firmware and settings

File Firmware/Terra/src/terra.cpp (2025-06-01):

/**
 * @file terra.cpp
 * @brief Entrypoint for Terra
 * @date 2025-04-20
 * 
 * @copyright Copyright (c) 2025
 * 
 */

#include <Arduino.h>
#include "terra.h"
#include "power.h"
#include "haptics.h"
#include "compass.h"
#include "navigation.h"
#include "display.h"


void setup() {
  esp_log_level_set("*", ESP_LOG_VERBOSE);  // or ESP_LOGV for verbose
  
  pinMode(PIN_DISPLAY_PWM_BL, OUTPUT);
  analogWrite(PIN_DISPLAY_PWM_BL, displayBrightness);  // 0 at fisrt init

  Serial.begin(115200);
  printf("========= TERRA =========\n");
  printf("sha:  %s\nat:   %s %s\n", GIT_COMMIT_ID, BUILD_DATE, BUILD_TIME);
  printf("=========================\n");
  
  printf("SDA: %d, SCL: %d\n", SDA, SCL);
  printf("I2C: %d\n", Wire.begin(SDA, SCL));

  // Power management
  initPower();

  // Haptic driver
  initHaptics();

  // Screen
  displayInit();

  // GPS
  initNav();

  // Compass
  initCompass();
  initCompassNoMotionDetection(TERRA_IDLE_SHUTDOWN_SEC);

  playEffect(HAP_EFFECT_PWRON); // power on sequence finsihed!
}

// Main Loop
void loop() {
  navUpdate();
  displayUpdate();

  batteryCheckVolatge();
  powerCheckButton();
  compassServiceInterrupts();
}

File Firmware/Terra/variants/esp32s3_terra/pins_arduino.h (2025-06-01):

#ifndef Pins_Arduino_h
#define Pins_Arduino_h

#include <stdint.h>
#include "soc/soc_caps.h"

#define USB_VID 0x303a
#define USB_PID 0x1AA1

// BUILTIN_LED can be used in new Arduino API digitalWrite() like in Blink.ino
static const uint8_t LED_BUILTIN = 48;
#define BUILTIN_LED  LED_BUILTIN // backward compatibility
#define LED_BUILTIN LED_BUILTIN  // allow testing #ifdef LED_BUILTIN


// ================================
// UART:    GPS
// ================================
static const uint8_t PIN_TX1 = 17;
static const uint8_t PIN_RX1 = 18;


// ================================
// I2C:     IMU, Compass, Haptics
// ================================
static const uint8_t SDA = 8;   // SDA used by Wire.cpp
static const uint8_t SCL = 9;   // SCL used by Wire.cpp


// ================================
// SPI:     Display
// ================================
#define SS 10
#define MOSI 11
#define MISO 13
#define SCK  12
// static const uint8_t SS    = 10;
// static const uint8_t MOSI  = 11;
// static const uint8_t MISO  = 13;
// static const uint8_t SCK   = 12;


// ================================
// GPIO:    Peripherals, etc.
// ================================
//  Battery
static const uint8_t PIN_BAT_VOLTAGE    = 1;

//  Display
#define PIN_DISPLAY_RST                   4    // active low display reset
#define PIN_DISPLAY_PWM_BL                5    // display pwm backlight
#define PIN_DISP_DC                       33   // display DC, using define to ensure TFT_eSPI driver is happy with its register-level GPIO access
// static const uint8_t PIN_DISPLAY_RST    = 4;    // active low display reset
// static const uint8_t PIN_DISPLAY_PWM_BL = 5;    // display pwm backlight
// static const uint8_t PIN_DISP_DC        = 33;   // display DC

//  Power Management
static const uint8_t PIN_PWR_SW         = 34;   // power switch input
static const uint8_t PIN_PWROFF         = 35;   // power off signal

//  Compass
static const uint8_t PIN_CMP_INT        = 37;   // compass interrupt
static const uint8_t PIN_CMP_RST        = 38;   // active low compass reset

//  GPS
static const uint8_t PIN_GPS_RST        = 39;   // active low GPS reset
static const uint8_t PIN_GPS_STBY       = 40;   // GPS standby mode
static const uint8_t PIN_GPS_FIX        = 41;   // GPS fix indicator

//  Haptics
static const uint8_t PIN_HAP_IN_TRIG    = 42;   // haptics in or trigger



// ================================
// GPIO:    UNUSED -- Legacy for
//          dev boards.
// ================================
// static const uint8_t A0 = 1;
// static const uint8_t A1 = 2;
// static const uint8_t A2 = 3;
// static const uint8_t A3 = 4;
// static const uint8_t A4 = 5;
// static const uint8_t A5 = 6;
// static const uint8_t A6 = 7;
// static const uint8_t A7 = 8;
// static const uint8_t A8 = 9;
// static const uint8_t A9 = 10;
// static const uint8_t A10 = 11;
// static const uint8_t A11 = 12;
// static const uint8_t A12 = 13;
// static const uint8_t A13 = 14;
// static const uint8_t A14 = 15;
// static const uint8_t A15 = 16;
// static const uint8_t A16 = 17;
// static const uint8_t A17 = 18;
// static const uint8_t A18 = 19;
// static const uint8_t A19 = 20;

// static const uint8_t T1 = 1;
// static const uint8_t T2 = 2;
// static const uint8_t T3 = 3;
// static const uint8_t T4 = 4;
// static const uint8_t T5 = 5;
// static const uint8_t T6 = 6;
// static const uint8_t T7 = 7;
// static const uint8_t T8 = 8;
// static const uint8_t T9 = 9;
// static const uint8_t T10 = 10;
// static const uint8_t T11 = 11;
// static const uint8_t T12 = 12;
// static const uint8_t T13 = 13;
// static const uint8_t T14 = 14;

#endif /* Pins_Arduino_h */

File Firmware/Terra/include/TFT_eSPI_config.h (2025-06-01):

#ifndef TFT_ESPI_CONFIG_H
#define TFT_ESPI_CONFIG_H

#include <Arduino.h>

#define DISABLE_ALL_LIBRARY_WARNINGS

#define USER_SETUP_LOADED 1

#define GC9A01_DRIVER             // TFT Driver IC type
#define TFT_MISO MISO             // TFT Data out
#define TFT_MOSI MOSI             // TFT Data in
#define TFT_SCLK SCK              // TFT Clock
#define TFT_CS SS                 // Chip select control pin
#define TFT_DC PIN_DISP_DC        // Data Command control pin
#define TFT_RST PIN_DISPLAY_RST   // Reset pin (could connect to RST pin)
// #define TFT_BL PIN_DISPLAY_PWM_BL // Backlight pin
#define TFT_BACKLIGHT_ON HIGH     // Backlight polarity
#define LOAD_GLCD    // Font 1. Original Adafruit 8 pixel font needs ~1820 bytes in FLASH
#define LOAD_FONT2   // Font 2. Small 16 pixel high font, needs ~3534 bytes in FLASH, 96 characters
#define LOAD_FONT4   // Font 4. Medium 26 pixel high font, needs ~5848 bytes in FLASH, 96 characters
#define LOAD_FONT6   // Font 6. Large 48 pixel font, needs ~2666 bytes in FLASH, only characters 1234567890:-.apm
#define LOAD_FONT7   // Font 7. 7 segment 48 pixel font, needs ~2438 bytes in FLASH, only characters 1234567890:.
#define LOAD_FONT8   // Font 8. Large 75 pixel font needs ~3256 bytes in FLASH, only characters 1234567890:-.
#define LOAD_GFXFF   // FreeFonts. Include access to the 48 Adafruit_GFX free fonts FF1 to FF48 and custom fonts
#define SMOOTH_FONT
#define TFT_WIDTH 240
#define TFT_HEIGHT 240
#define SPI_FREQUENCY 40000000
#define SPI_READ_FREQUENCY 20000000
#define SPI_TOUCH_FREQUENCY 2500000
// #define SPI_FREQUENCY 27000000
// #define SPI_READ_FREQUENCY 20000000
// #define SPI_TOUCH_FREQUENCY 2500000

#endif

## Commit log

2025-03-16 Create project
    [Terra-HW.kicad_pcb, Terra-HW.kicad_sch]
2025-03-16 Added MCU and started power section.
    [Microcontroller.kicad_sch, Power.kicad_sch, Terra-HW.kicad_sch]
2025-03-16 Added power latch circuit.
    [Microcontroller.kicad_sch, Power.kicad_sch, Terra-HW.kicad_sch]
2025-03-24 SCH and PCB updates. Added Integrated GPS and other features.
    [ESP32-S3-MINI-1-N8.step, JST_PH_B8B-PH-SM4-TB_Vertical.STEP, KMR231NGULCLFS.stp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]
2025-04-03 Updated board outline to version 004
    [Microcontroller.kicad_sch, Peripherals.kicad_sch, Power.kicad_sch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]
2025-04-03 Component placement for -004 board outline.
    [KSS221GLFS.stp, KSS323GLFG.stp, Microcontroller.kicad_sch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]
2025-04-05 Lots of board layout
    [Microcontroller.kicad_sch, Peripherals.kicad_sch, Power.kicad_sch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]
2025-04-05 More layout and sch updates, ready for final review.
    [Microcontroller.kicad_sch, Peripherals.kicad_sch, Power.kicad_sch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]
2025-04-06 For design review X01-001 Ammendment: Changed ALL VIAS to 0.3/0.55 to reduce fab cost. Signed-off-by: James Mendel <jrm.mendel@gmail.com>
    [Microcontroller.kicad_sch, Peripherals.kicad_sch, Power.kicad_sch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]
2025-04-07 Release X01-003 - Added "JRM" logo to L3 and and Modem Works logo to L4. - Upated copyright - Added alternates for some components - Some cleanup on SCH and PCB.
    [Microcontroller.kicad_sch, Peripherals.kicad_sch, Power.kicad_sch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]
2025-04-08 Release X01-004 - Reduced size of 0.3mm pad / 0.2mm pitch to increase pitch to >0.22mm - Removed via-in-pad
    [Power.kicad_sch, Terra-HW.csv, Terra-HW.kicad_pcb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]
2025-04-20 Implement BNO055 compass driver
2025-04-20 Create power manager
2025-04-20 Remove blockers from power ISRs
2025-04-20 clean power.cpp
2025-04-20 Refactor display driver
2025-04-22 refactor: minor cleanup prints / comments
2025-05-20 remove button ISR to fix debounce
    [power.cpp, power.h]
2025-06-01 bringup: power tweaks
2025-06-01 bringup: pin definition updates
2025-06-01 bringup: GPS (disabled internal GPS due to antenna issue)
    [navigation.cpp, navigation.h]
2025-06-09 fixed esp32-s3 symbol GPIO8
    [Microcontroller.kicad_sch, Terra-HW.kicad_sch]
2025-06-09 sch: flip battery connector. The connector did not align with the pinout of the battery, requiring us to flip the connector. CAUTION: If upgrading from Terra X01 to X02, flip back the connector leads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
    [Power.kicad_sch]
2025-06-15 update board outline and flip 180
    [250506_Terra PCB Outline Only.dxf, 250506_Terra PCB Outline.dxf, Peripherals.kicad_sch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]
2025-06-15 sch: replace gps for TESSO-LIV3R
    [Peripherals.kicad_sch, Power.kicad_sch, Terra-HW.kicad_pcb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]
2025-06-16 pcb: initial layout of TESSO gps
    [Peripherals.kicad_sch, TESEO-LIV3R.stp, Terra-HW.kicad_pcb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]
2025-06-16 pcb: other cleanup
    [Terra-HW.kicad_pcb]
2025-06-16 pcb: gps cleanup
    [Terra-HW.kicad_pcb]
2025-06-22 sch: change USB Detect to SN74LVC1G14
    Removed N-FET used, which had a problem of restarting the device
    after powerdown when only powered by battery (no USB)
    [Microcontroller.kicad_sch, Power.kicad_sch]
2025-06-22 pcb: move power connector in from edge 1mm
    [Terra-HW.kicad_pcb, Terra-HW.kicad_sch]
2025-06-22 pcb: route new pwroff signals
    [Terra-HW.kicad_pcb]
2025-06-27 pcb: move back graphics and tp. remove MISO tp.
    [Microcontroller.kicad_sch, Terra-HW.kicad_pcb, Terra-HW.kicad_sch]
2025-08-29 sch: change GPS to Adafruit PA1616D
    [Peripherals.kicad_sch, Terra-HW.kicad_sch]
2025-08-29 sch: updates
    [Microcontroller.kicad_sch, Peripherals.kicad_sch, Power.kicad_sch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]
2025-08-29 sch/pcb: add and link footprint for PA1616D
    [Peripherals.kicad_sch]
2025-08-29 pcb: position + link 3d model for gps
    [Terra-HW.kicad_pcb]
2025-09-03 component placement 2SEPT2025 for P&T
    [PA1616D.STEP, Terra-HW.kicad_pcb]
2025-09-03 pcb: more layout; sch: remove gps_stby signal
    [Microcontroller.kicad_sch, Peripherals.kicad_sch, Terra-HW.kicad_pcb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]
2025-09-04 pcb: finishing layout. resolved most drc's
    [Terra-HW.kicad_pcb]
2025-09-07 pcb: final route + cleanup. sch: dnp gps conn.
    [Microcontroller.kicad_sch, Peripherals.kicad_sch, Terra-HW.kicad_pcb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]
2025-09-07 pcb: cleanup
    [Terra-HW.kicad_pcb]
2025-09-09 pcb: minor tweak, send for design review X02-002
    [Terra-HW.kicad_pcb]
2025-09-10 pcb: remove Modem logo from bottom layer
    [Terra-HW.kicad_pcb]
2025-09-16 sch/pb: tweaks for X02-001 release, submit to vendor
    [Peripherals.kicad_sch, Power.kicad_sch, Terra-HW.kicad_pcb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]
2025-10-22 Release X02-002 - remove via in pad near J2 - decrease pad size on U9 due to solder web constraint
    [Terra-HW.kicad_pcb, Terra-HW.kicad_sch]

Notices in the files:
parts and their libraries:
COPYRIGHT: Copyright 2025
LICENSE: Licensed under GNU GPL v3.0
